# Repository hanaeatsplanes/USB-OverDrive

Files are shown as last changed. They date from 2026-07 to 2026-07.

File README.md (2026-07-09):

# USB OverDrive
> youll never need another dongle






## What even is this??

This is a USB-C -> 3x USB-A hub!

This uses:
* TUSB4041l as the main Hub
* 3x LP5912 as an LDO
* A male USB-C plug (JAE DX07P024AJ1) no need to worry about cables

## Why does this exist??

**This project was funded by [Hack Club Outpost](https://outpost.hackclub.com)!**

As a MacBook user, I deseperately need a dongle. I decided to design my own Hack Club themed dongle!

## Images











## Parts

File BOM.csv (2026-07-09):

Category | Item |  | Qty | Price | Link
PCB |  |  |  | $15.00 | https://jlcpcb.com
 | PCB Prototype |  | 5 | $15.00
 | PCBA |  | 2 | $128.27
 | Shipping |  | 1 | $12.54
 |  | Components (24 items) |  | $128.27
Components
 | JLCPCB |  |  | $36.54 | https://jlcpcb.com/parts
 |  | 10µF 0402 capacitor | 20 | $0.80 | https://jlcpcb.com/partdetail/16204-CL05A106MQ5NUNC/C15525
 |  | 1nF 0402 capacitor | 20 | $0.23 | https://jlcpcb.com/partdetail/1875-0402B102K500NT/C1523
 |  | 1µF 0402 capacitor | 24 | $0.63 | https://jlcpcb.com/partdetail/53938-CL05A105KA5NQNC/C52923
 |  | 18pF 0402 capacitor | 20 | $0.16 | https://jlcpcb.com/partdetail/1901-0402CG180J500NT/C1549
 |  | 100nF 0402 capacitor | 56 | $0.71 | https://jlcpcb.com/partdetail/1877-CL05B104KO5NNNC/C1525
 |  | 150µF 1206 capacitor | 6 | $6.15 | https://jlcpcb.com/partdetail/548784-GRM31CR60J157ME11L/C528968
 |  | 220Ω@100MHz 0201 ferrite bead | 20 | $0.08 | https://jlcpcb.com/partdetail/Sunlord-GZ0603D221TF/C185895
 |  | USB-A receptacle | 6 | $0.39 | https://jlcpcb.com/partdetail/43613-905361A2031D10101/C42622
 |  | JAE DX07P024AJ1 USB-C plug | 2 | $1.84 | https://jlcpcb.com/partdetail/JAEElectronics-DX07P024AJ1R1500/C5352764
 |  | 5.1kΩ 0402 resistor | 20 | $0.03 | https://jlcpcb.com/partdetail/26648-0402WGF5101TCE/C25905
 |  | 25.5kΩ 0402 resistor 5% | 20 | $0.04 | https://jlcpcb.com/partdetail/FOJAN-FRC0402F2552TS/C2998160
 |  | 90.9kΩ 0402 resistor 1% | 20 | $0.04 | https://jlcpcb.com/partdetail/FOJAN-FRC0402F9092TS/C2998102
 |  | 10kΩ 0402 resistor 1% | 20 | $0.50 | https://jlcpcb.com/partdetail/YAGEO-RT0402BRE0710KL/C513708
 |  | 9.53kΩ 0402 resistor 1% | 20 | $0.04 | https://jlcpcb.com/partdetail/FOJAN-FRC0402F9531TS/C5126160
 |  | 4.7kΩ 0402 resistor 5% | 20 | $0.02 | https://jlcpcb.com/partdetail/FOJAN-FRC0402J472TS/C2906941
 |  | 4.7kΩ 0402 resistor | 20 | $0.12 | https://jlcpcb.com/partdetail/26643-0402WGF4701TCE/C25900
 |  | 1MΩ 0402 resistor | 20 | $0.03 | https://jlcpcb.com/partdetail/26826-0402WGF1004TCE/C26083
 |  | LP5912-5.0 WSON-6 LDO | 2 | $1.84 | https://jlcpcb.com/partdetail/TexasInstruments-LP5912_50DRVR/C2761351
 |  | LP5912-3.3 WSON-6 LDO | 2 | $1.53 | https://jlcpcb.com/partdetail/TexasInstruments-LP5912_33DRVR/C524780
 |  | TPS2561 WSON-10 power switch | 4 | $3.61 | https://jlcpcb.com/partdetail/TexasInstruments-TPS2561DRCR/C140303
 |  | LP5912-1.2 WSON-6 LDO | 2 | $1.80 | https://jlcpcb.com/partdetail/TexasInstruments-LP5912_12DRVR/C2876233
 |  | TUSB4041I HTQFP-64 USB hub controller | 2 | $15.28 | https://jlcpcb.com/partdetail/TexasInstruments-TUSB4041IPAPQ1/C2879403
 |  | 24MHz 3225 crystal | 6 | $0.66 | https://jlcpcb.com/partdetail/YXC_CrystalOscillators-X322524MRB4SI/C70571
 |  | 10kΩ 0402 resistor 5% | 20 | $0.01 | https://jlcpcb.com/partdetail/455452-RC02K103JT/C453512

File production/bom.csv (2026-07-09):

Designator | Footprint | Quantity | Value | LCSC Part #
C1, C25, C37 | 0402 | 3 | 10uF
C10, C12, C22, C23, C24, C4, C7 | 0402 | 7 | 1uF
C11, C13 | 0402 | 2 | 18pF
C14, C16, C17, C2, C26, C27, C28, C29, C30, C31, C32, C33, C34, C35, C36, C38, C39, C40, C50, C51, C52, C8, C9 | 0402 | 23 | 0.1uF
C18, C20, C21 | 1206 | 3 | 150uF
C3, C54, C55, C56 | 0402 | 4 | 0.001uF
FB1, FB2, FB3, FB4, FB5 | 0201 | 5 | 220 @ 100 MHz
J5, J6, J7 | USB-A-TH_C42622 | 3 | USB_A | C42622
P2 | USB_C_Plug_JAE_DX07P024AJ1 | 1 | USB_C_Plug_USB2.0
R1 | 0402 | 1 | 5.1K
R10 | 0402 | 1 | 90.9K 0402 1%
R11 | 0402 | 1 | 10K 0402 1%
R12 | 0402 | 1 | 9.53K 0402 1%
R13, R14, R15 | 0402 | 3 | 4.7K 0402 5%
R16 | 0402 | 1 | 4.7K
R17, R18, R19, R2, R3 | 0402 | 5 | 1M
R4, R5 | 0402 | 2 | 25.5K 0402 5%
R6, R7, R8 | 0402 | 3 | 10K 0402 5%
U1 | WSON-6-1EP_2x2mm_P0.65mm_EP1x1.6mm_ThermalVias | 1 | 5.0V
U2 | WSON-6-1EP_2x2mm_P0.65mm_EP1x1.6mm_ThermalVias | 1 | 3.3V
U3, U4 | VSON-10-1EP_3x3mm_P0.5mm_EP1.65x2.4mm_ThermalVias | 2 | TPS2561
U5 | WSON-6-1EP_2x2mm_P0.65mm_EP1x1.6mm_ThermalVias | 1 | 1.2V
U7 | HTQFP-64-1EP_10x10mm_P0.5mm_EP8x8mm_Mask4.4x4.4mm_ThermalVias | 1 | TUSB4041I
Y1 | Crystal_SMD_3225-4Pin_3.2x2.5mm | 1 | Crystal_GND24

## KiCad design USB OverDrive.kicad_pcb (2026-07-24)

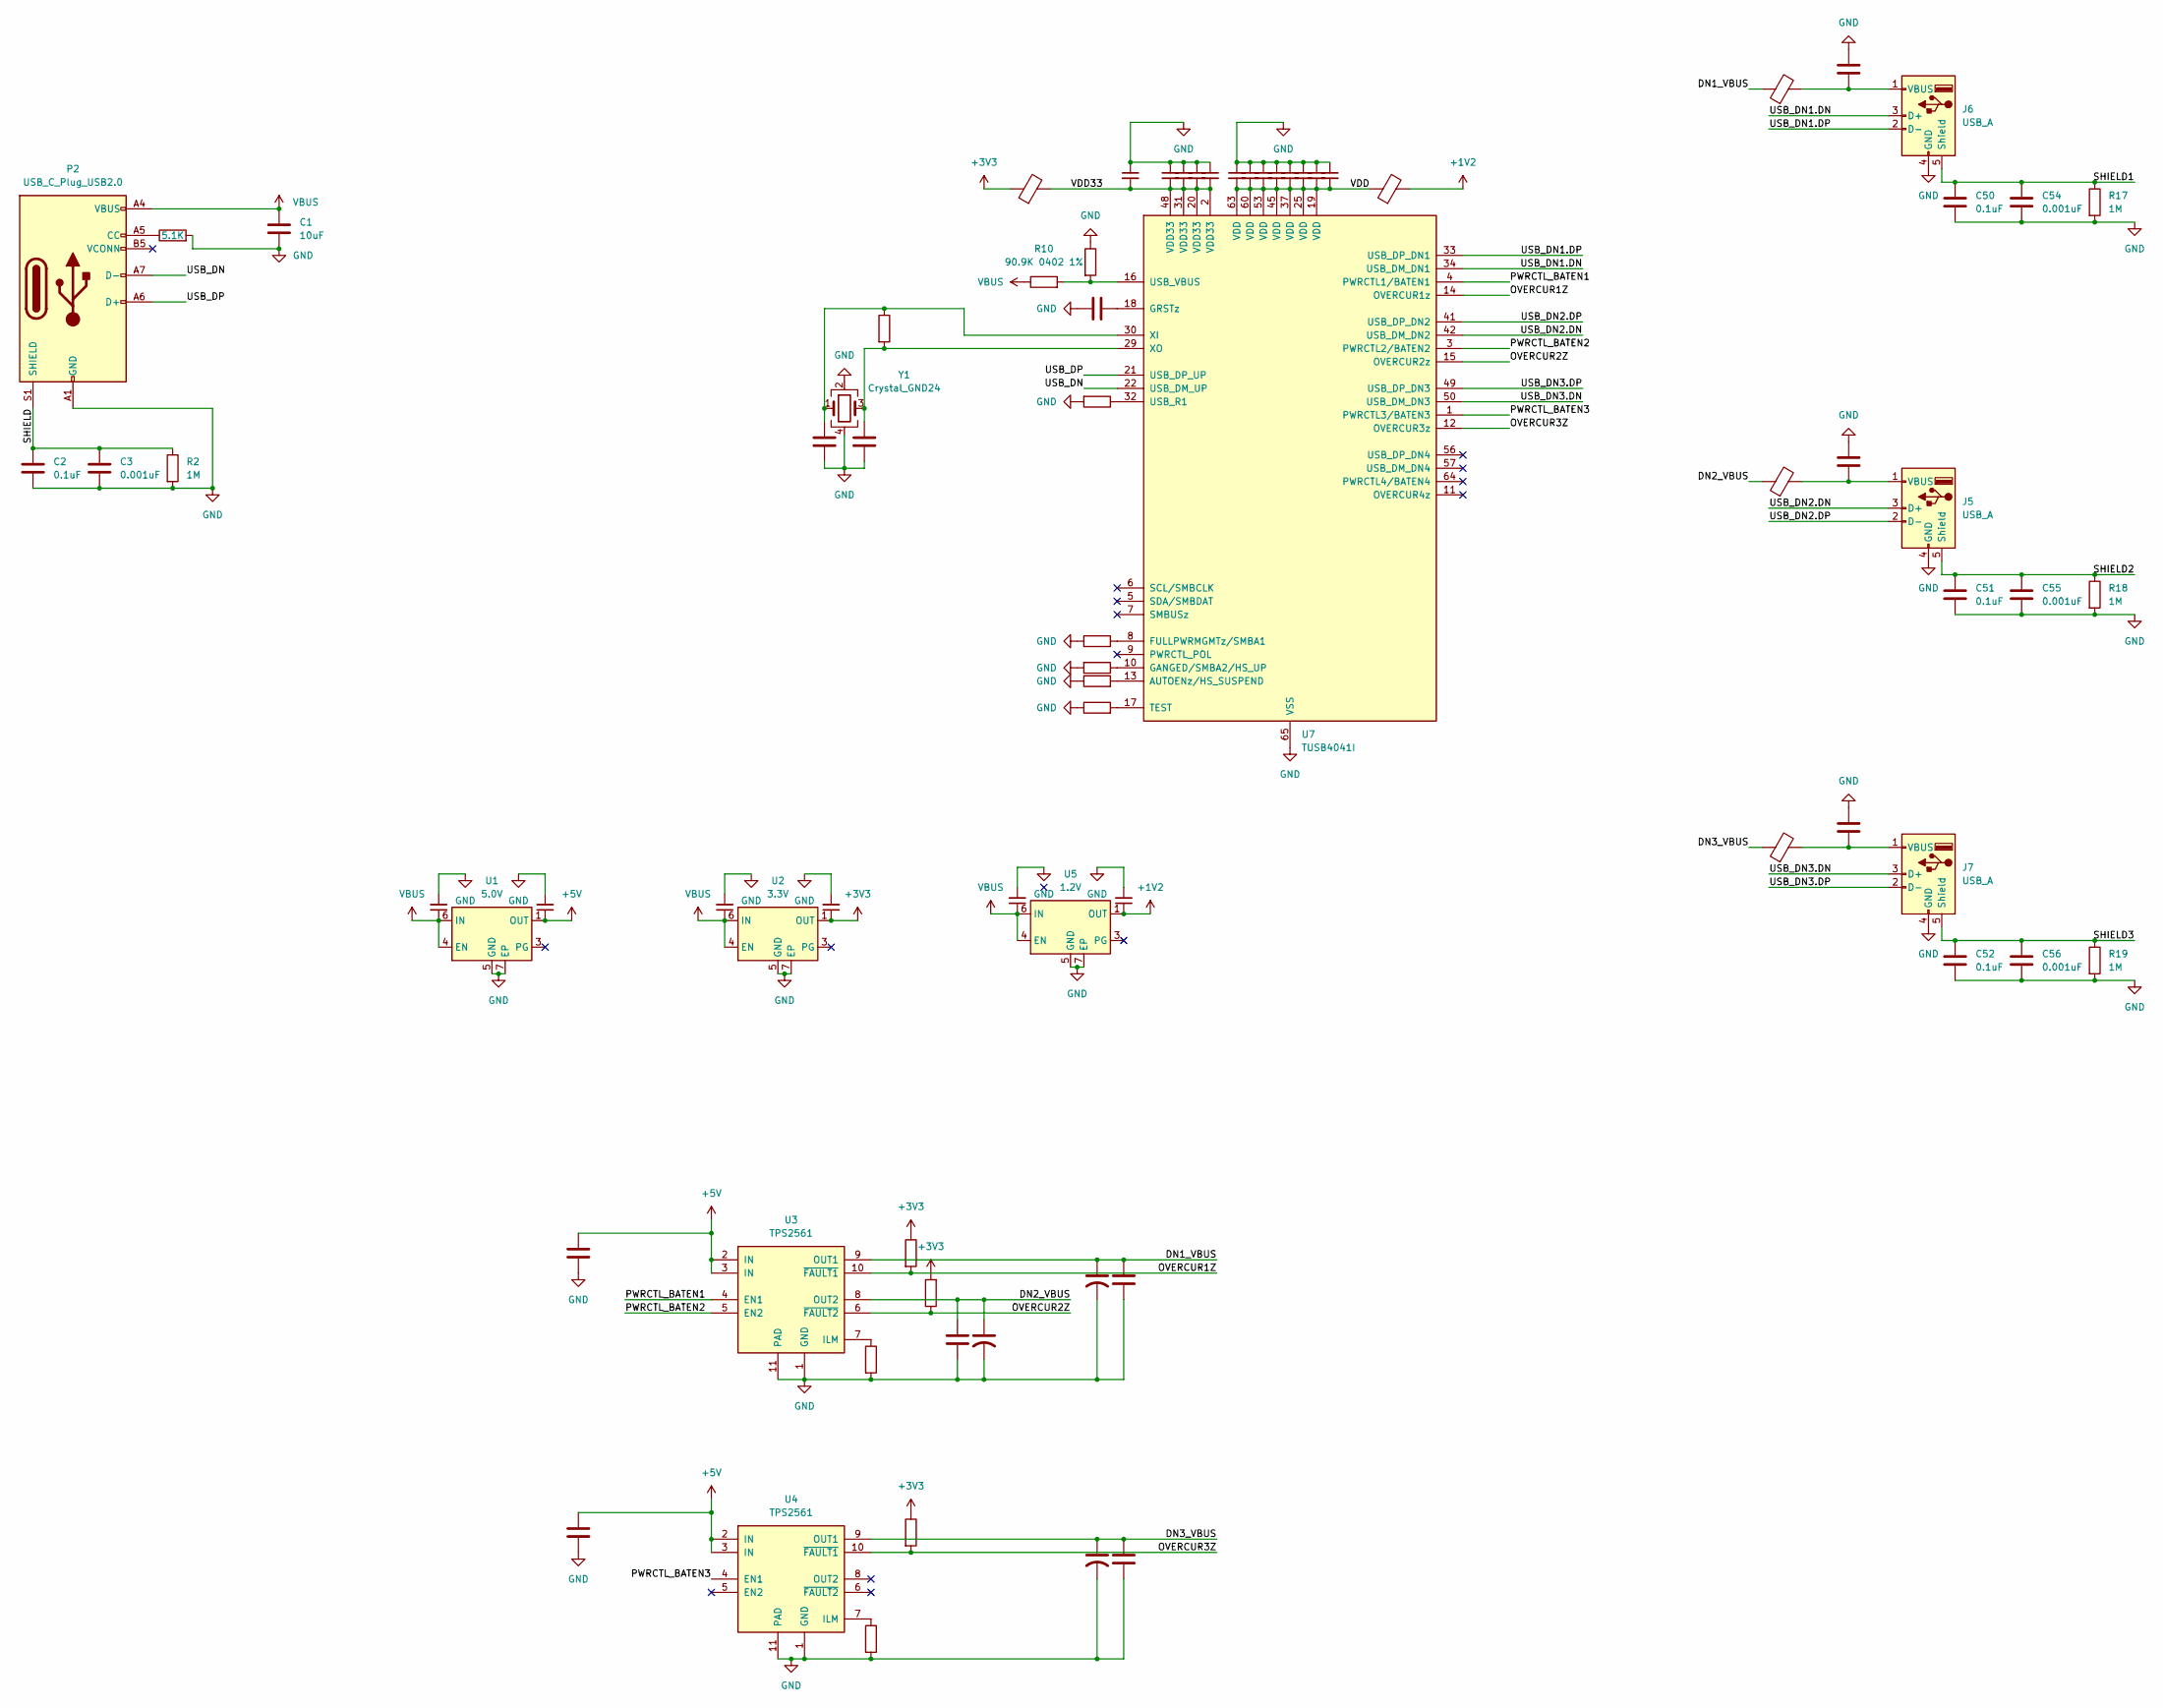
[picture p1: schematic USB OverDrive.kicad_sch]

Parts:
C1, C25, C37: 10uF; C_0402_1005Metric
C2, C8, C9, C14, C16, C17, C26, C27, C28, C29, C30, C31, C32, C33, C34, C35, C36, C38, C39, C40, C50, C51, C52: 0.1uF; C_0402_1005Metric
C3, C54, C55, C56: 0.001uF; C_0402_1005Metric
C4, C7, C10, C12, C22, C23, C24: 1uF; C_0402_1005Metric
C11, C13: 18pF; C_0402_1005Metric
C18, C20, C21: 150uF; C_1206_3216Metric
FB1, FB2, FB3, FB4, FB5: 220 @ 100 MHz; L_0201_0603Metric
J5, J6, J7: USB_A; USB-A-TH_C42622
P2: USB_C_Plug_USB2.0; USB_C_Plug_JAE_DX07P024AJ1
R1: 5.1K; R_0402_1005Metric
R2, R3, R17, R18, R19: 1M; R_0402_1005Metric
R4, R5: 25.5K 0402 5%; R_0402_1005Metric
R6, R7, R8: 10K 0402 5%; R_0402_1005Metric
R10: 90.9K 0402 1%; R_0402_1005Metric
R11: 10K 0402 1%; R_0402_1005Metric
R12: 9.53K 0402 1%; R_0402_1005Metric
R13, R14, R15: 4.7K 0402 5%; R_0402_1005Metric
R16: 4.7K; R_0402_1005Metric
U1: 5.0V; WSON-6-1EP_2x2mm_P0.65mm_EP1x1.6mm_ThermalVias
U2: 3.3V; WSON-6-1EP_2x2mm_P0.65mm_EP1x1.6mm_ThermalVias
U3, U4: TPS2561; VSON-10-1EP_3x3mm_P0.5mm_EP1.65x2.4mm_ThermalVias
U5: 1.2V; WSON-6-1EP_2x2mm_P0.65mm_EP1x1.6mm_ThermalVias
U7: TUSB4041I; HTQFP-64-1EP_10x10mm_P0.5mm_EP8x8mm_Mask4.4x4.4mm_ThermalVi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
Y1: Crystal_GND24; Crystal_SMD_3225-4Pin_3.2x2.5mm

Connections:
+1V2: C24.1, FB2.2, U5.1 (OUT)
+5V: C7.1, C8.1, C9.1, U1.1 (OUT), U3.2 (IN), U3.3 (IN), U4.2 (IN), U4.3 (IN)
/DN1_VBUS: C16.1, C20.1, FB3.1, U3.9 (OUT1)
/DN2_VBUS: C17.1, C21.1, FB4.1, U3.8 (OUT2)
/DN3_VBUS: C14.1, C18.1, FB5.1, U4.9 (OUT1)
/OVERCUR2Z: R7.1, U3.6 (~FAULT2), U7.15 (OVERCUR2z)
/OVERCUR3Z: R8.2, U4.10 (~FAULT1), U7.12 (OVERCUR3z)
/PWRCTL_BATEN1: U3.4 (EN1), U7.4 (PWRCTL1/BATEN1)
/PWRCTL_BATEN2: U3.5 (EN2), U7.3 (PWRCTL2/BATEN2)
/PWRCTL_BATEN3: U4.4 (EN1), U7.1 (PWRCTL3/BATEN3)
/SHIELD: C2.1, C3.1, P2.S1 (SHIELD), R2.1
/SHIELD1: C50.1, C54.1, J6.5 (Shield), R17.1
/SHIELD2: C51.1, C55.1, J5.5 (Shield), R18.1
/SHIELD3: C52.1, C56.1, J7.5 (Shield), R19.1
/USB_DN: P2.A7 (D-), U7.22 (USB_DM_UP)
/USB_DN1.DN: J6.3 (D+), U7.34 (USB_DM_DN1)
/USB_DN1.DP: J6.2 (D-), U7.33 (USB_DP_DN1)
/USB_DN2.DN: J5.3 (D+), U7.42 (USB_DM_DN2)
/USB_DN2.DP: J5.2 (D-), U7.41 (USB_DP_DN2)
/USB_DN3.DN: J7.3 (D+), U7.50 (USB_DM_DN3)
/USB_DN3.DP: J7.2 (D-), U7.49 (USB_DP_DN3)
/USB_DP: P2.A6 (D+), U7.21 (USB_DP_UP)
/VDD: C30.2, C31.2, C32.2, C33.2, C34.2, C35.2, C36.2, C37.2, FB2.1, U7.19 (VDD), U7.25 (VDD), U7.37 (VDD), U7.45 (VDD), U7.53 (VDD), U7.60 (VDD), U7.63 (VDD)
/VDD33: C25.2, C26.2, C27.2, C28.2, C29.2, FB1.2, U7.2 (VDD33), U7.20 (VDD33), U7.31 (VDD33), U7.48 (VDD33)
GND: C1.2, C2.2, C3.2, C4.2, C7.2, C8.2, C9.2, C10.2, C11.1, C12.2, C13.1, C14.2, C16.2, C17.2, C18.2, C20.2, C21.2, C22.2, C23.1, C24.2, C25.1, C26.1, C27.1, C28.1, C29.1, C30.1, C31.1, C32.1, C33.1, C34.1, C35.1, C36.1, C37.1, C38.1, C39.1, C40.1, C50.2, C51.2, C52.2, C54.2, C55.2, C56.2, J5.4 (GND), J6.4 (GND), J7.4 (GND), P2.A1 (GND), P2.A12 (GND), P2.B1 (GND), P2.B12 (GND), R1.2, R2.2, R4.2, R5.2, R11.1, R12.2, R13.1, R14.1, R15.1, R16.2, R17.2, R18.2, R19.2, U1.5 (GND), U1.7 (EP), U2.5 (GND), U2.7 (EP), U3.1 (GND), U3.11 (PAD), U4.1 (GND), U4.11 (PAD), U5.5 (GND), U5.7 (EP), U7.65 (VSS), Y1.2, Y1.4
unnamed: C39.2, FB4.2, J5.1 (VBUS)
unnamed: C38.2, FB3.2, J6.1 (VBUS)
unnamed: C40.2, FB5.2, J7.1 (VBUS)
unnamed: P2.A5 (CC), R1.1
unnamed: R4.1, U3.7 (ILM)
unnamed: R5.1, U4.7 (ILM)
unnamed: R13.2, U7.13 (AUTOENz/HS_SUSPEND)
unnamed: R15.2, U7.8 (FULLPWRMGMTz/SMBA1)
unnamed: R16.1, U7.10 (GANGED/SMBA2/HS_UP)
unnamed: C23.2, U7.18 (GRSTz)
unnamed: R14.2, U7.17 (TEST)
unnamed: R12.1, U7.32 (USB_R1)
unnamed: R10.2, R11.2, U7.16 (USB_VBUS)
unnamed: C11.2, R3.1, U7.30 (XI), Y1.1
unnamed: C13.2, R3.2, U7.29 (XO), Y1.3
VBUS: C1.1, C4.1, C10.1, C22.1, P2.A4 (VBUS), P2.A9 (VBUS), P2.B4 (VBUS), P2.B9 (VBUS), R10.1, U1.4 (EN), U1.6 (IN), U2.4 (EN), U2.6 (IN), U5.4 (EN), U5.6 (IN)

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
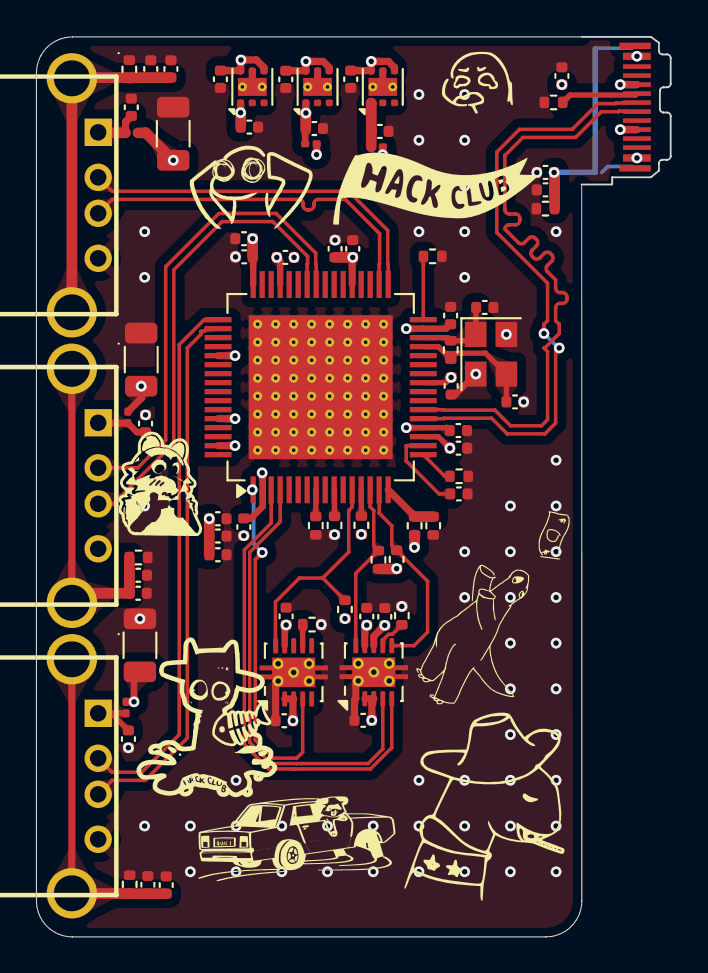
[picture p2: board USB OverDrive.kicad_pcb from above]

Board: 4 copper layers, 35.2 x 50.0 mm, 76 parts (0 on the bottom side), 43 nets.

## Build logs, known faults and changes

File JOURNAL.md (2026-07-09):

# USB OverDrive — Journal Export

Total Time: 9 hours

- Exported at: 2026-07-06T19:14:23Z
- Project ID: 4151
- Entries: 2

## Entry 1
- ID: 10902
- Author: hna
- Created At: 2026-06-01T14:53:00Z

### Content



I got started on USB OverDrive, a 4x USB A to USB C hub that I desperately need. I got started on wiring the USBC Port.

### Recording Links

- https://lookout.hackclub.com/api/media/ab3e0b4f-c1d9-4abd-971e-3779129b476f/video.mp4

## Entry 2
- ID: 11378
- Author: hna
- Created At: 2026-06-03T13:37:45Z

### Content

Worked on powering the TUSB chip, added capacitors, changed to 4 layer for easyness, added pull down resistors on PCB


### Recording Links

- https://lookout.hackclub.com/api/media/5371de7c-b3ce-4119-b6cf-2f0ea3e6ad0d/video.mp4

---

# USB OverDrive - Outpost Revive

Total Time: 2h (lookout)

## Day 1: July 6th
Start Time: 3:00 PM
End Time: 12:00 AM
Elapsed Time: 3 hours

I'm gonna restart this project!

I'm gonna remove the 3.0 functionality, i don't particularly care about it since this will only be for mouses and drives and stuff.



looking good :D

time to route! 





pcbing it

## Day 2: July 7th



soo the purple highlighted square is how big maximum this thing can be
and i am very outside that range

i'm gonna have to remove one of the USB's, i dont think i'll be able to make it fit :<

## Day 3: July 8th

all of today i have been suffering with edge.cuts layers. why is kicad so difficult.

anyway, after getting those DRC errors fixed, im starting to work on traces:



i have the crystal and power from the upstream(? the one that goes to the laptop) done, so i just need to route D± to the TUSB and route the downstream(?) USBA ones



I finished routing everything!!! omg peak... i did not expect to get this far in today, although i do have some unconnected ground zones whoops... ill fix those tmmr and ship !!!

## Day 3: July 8th

it turns out that JLCPCB doesnt stock the LP5912-1.1DRV... changing it to 1.2V is well within the maximum range that TI is okay with, so i'm doing that

okay so today i:
* "fixed" all my DRC errors
* * turns out most of them are just kicad being stingy, jlcpcb will do just fine patpatpat
* added some dope ass silkscreen


* made everything ship-ready :D

i should be able to ship today :3

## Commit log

2026-07-07 my life is a pahtay
    [USB OverDrive.kicad_pcb, USB OverDrive.kicad_sch]
2026-07-08 Update JOURNAL.md with Day 3 progress
    Documented struggles with edge cuts layers in KiCad and progress on routing traces.
2026-07-09 Finish routing components in JOURNAL.md
    Completed routing of components and noted unconnected ground zones to fix later.
2026-07-09 fix drc
    [USB OverDrive.kicad_pcb]
2026-07-09 Add shipping row to BOM.csv
    [BOM.csv]
2026-07-24 add qr
    [USB OverDrive.kicad_pcb, designators.csv]
